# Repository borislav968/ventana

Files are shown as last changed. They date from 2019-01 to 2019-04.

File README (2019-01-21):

This folder contains the crank power window controller firmware source code and PCB design.

This controller replaces the crank window mechanism and is intended to be applied in retro cars where the owner
doesn't want to install the buttons when installing the power window drive.

The main features are:
- soft motor start and stop.
- full opening or closing mode without holding the lever.
- an input from the car alarm or central lock system for closing the windows.
- protection from motor overload or short circuit with a current sensor.
- protection from output short circuit to the ground or battery.

© Boris Malkov 2019

This program is free software: you can redistribute it and/or modify
    it under the terms of the GNU General Public License as published by
    the Free Software Foundation, either version 3 of the License, or
    (at your option) any later version.

    This program is distributed in the hope that it will be useful,
    but WITHOUT ANY WARRANTY; without even the implied warranty of
    MERCHANTABILITY or FITNESS FOR A PARTICULAR PURPOSE.  See the
    GNU General Public License for more details.

    You should have received a copy of the GNU General Public License
    along with this program.  If not, see <https://www.gnu.org/licenses/>.

В этой папке находятся исходные тексты ПО и чертежи печатной платы контроллера электростеклоподъёмника.

Контроллер устанавливается на место штатного механизма ручного стеклоподъёмника и использует его поворотную рукоятку,
прездназначен для установки на ретро-автомобили, где использование кнопок неуместно.

Основные функции:
- плавный пуск и остановка двигателя привода.
- доводка до полного открытия и закрытия без удерживания рукоятки.
- вход для подключения к охранной системе или центральному замку для закрытия окон.
- зашита от перегрузки или КЗ электродвигателя.
- защита от замыкания выходов на массу или плюсовой провод.

© Борис Мальков 2019

Это свободная программа: вы можете перераспространять ее и/или изменять
   ее на условиях Стандартной общественной лицензии GNU в том виде, в каком
   она была опубликована Фондом свободного программного обеспечения; либо
   версии 3 лицензии, либо (по вашему выбору) любой более поздней версии.

   Эта программа распространяется в надежде, что она будет полезной,
   но БЕЗО ВСЯКИХ ГАРАНТИЙ; даже без неявной гарантии ТОВАРНОГО ВИДА
   или ПРИГОДНОСТИ ДЛЯ ОПРЕДЕЛЕННЫХ ЦЕЛЕЙ. Подробнее см. в Стандартной
   общественной лицензии GNU.

   Вы должны были получить копию Стандартной общественной лицензии GNU
   вместе с этой программой. Если это не так, см.
   <https://www.gnu.org/licenses/>.

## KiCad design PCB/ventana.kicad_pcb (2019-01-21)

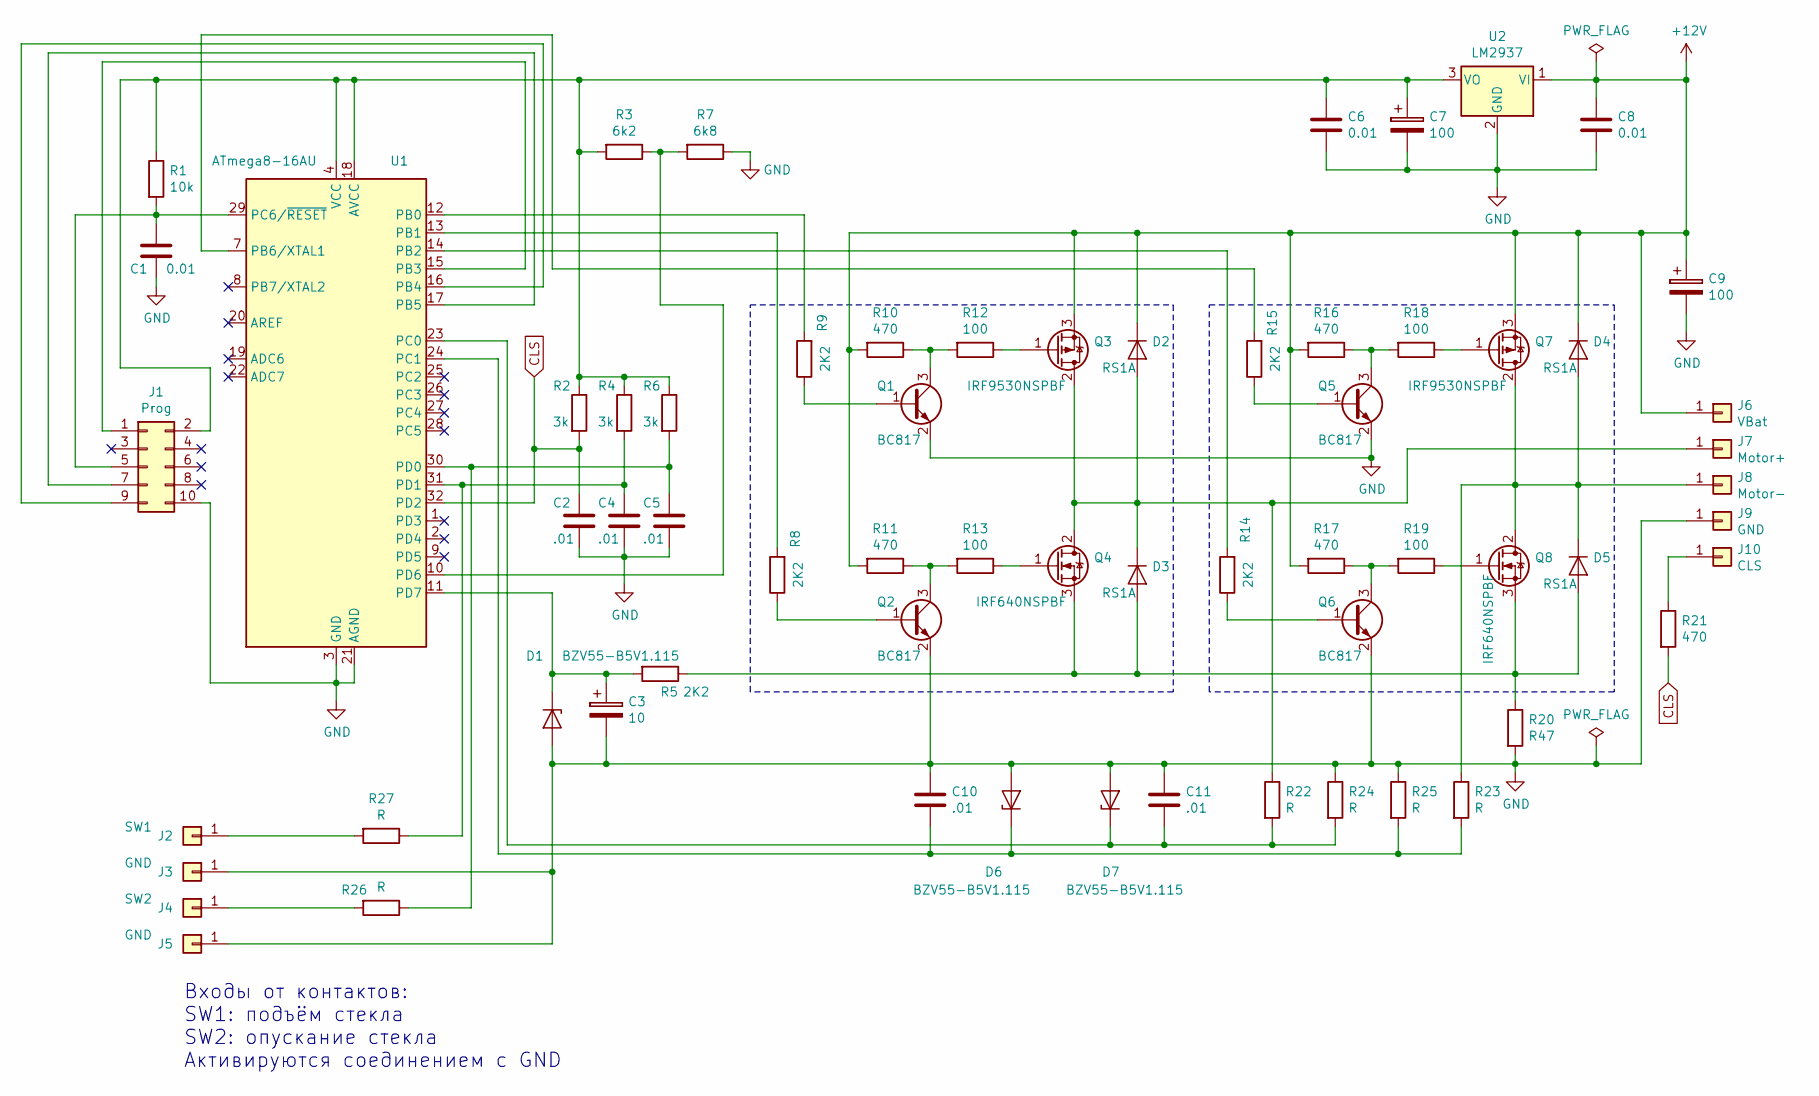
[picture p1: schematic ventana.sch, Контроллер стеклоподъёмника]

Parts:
C1, C6, C8: 0.01; C_1206_3216Metric
C2, C4, C5, C10, C11: .01; C_1206_3216Metric
C3: 10; CP_Elec_5x5.3
C7, C9: 100; CP_Elec_8x6.9
D1, D6, D7: BZV55-B5V1.115; D_SOD-123
D2, D3, D4, D5: RS1A; D_SMA
J1: Prog; conn_2_5
J2: SW1; PinHeader_1x01_P2.54mm_Vertical
J3, J5, J9: GND; PinHeader_1x01_P2.54mm_Vertical
J4: SW2; PinHeader_1x01_P2.54mm_Vertical
J6: VBat; PinHeader_1x01_P2.54mm_Vertical
J7: Motor+; PinHeader_1x01_P2.54mm_Vertical
J8: Motor-; PinHeader_1x01_P2.54mm_Vertical
J10: CLS; PinHeader_1x01_P2.54mm_Vertical
Q1, Q2, Q5, Q6: BC817; SOT-23
Q3, Q7: IRF9530NSPBF; TO-263-2
Q4, Q8: IRF640NSPBF; TO-263-2
R1: 10k; R_1206_3216Metric
R2, R4, R6: 3k; R_1206_3216Metric
R3: 6k2; R_1206_3216Metric
R5, R8, R9, R14, R15: 2K2; R_1206_3216Metric
R7: 6k8; R_1206_3216Metric
R10, R11, R16, R17, R21: 470; R_1206_3216Metric
R12, R13, R18, R19: 100; R_1206_3216Metric
R20: R47; R_Axial_Power_L25.0mm_W9.0mm_P30.48mm
R22, R23, R24, R25, R26, R27: R; R_1206_3216Metric
U1: ATmega8-16AU; AtMega8_TQFP32
U2: LM2937; SOT-223

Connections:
+12V: C8.1, C9.1, D2.1 (K), D4.1 (K), J6.1, Q3.3 (S), Q7.3 (S), R10.2, R11.2, R16.2, R17.2, U2.1 (VI)
CLS: C2.1, R2.2, R21.2, U1.32 (PD2)
GND: C1.2, C2.2, C3.2, C4.2, C5.2, C6.2, C7.2, C8.2, C9.2, C10.1, C11.1, D1.2 (A), D6.2 (A), D7.2 (A), J1.10, J3.1, J5.1, J9.1, Q1.2 (E), Q2.2 (E), Q5.2 (E), Q6.2 (E), R7.1, R20.2, R24.1, R25.1, U1.3 (GND), U1.5 (GND), U1.21 (AGND), U2.2 (GND)
unnamed: C1.1, J1.5, R1.2, U1.29 (PC6/~RESET)
unnamed: C3.1, D1.1 (K), R5.2, U1.11 (PD7)
unnamed: C4.1, R4.2, R27.1, U1.31 (PD1)
unnamed: C5.1, R6.2, R26.1, U1.30 (PD0)
unnamed: C6.1, C7.1, J1.2, R1.1, R2.1, R3.2, R4.1, R6.1, U1.4 (VCC), U1.6 (VCC), U1.18 (AVCC), U2.3 (VO)
unnamed: C10.2, D6.1 (K), R23.2, R25.2, U1.24 (PC1)
unnamed: C11.2, D7.1 (K), R22.2, R24.2, U1.23 (PC0)
unnamed: D2.2 (A), D3.1 (K), J7.1, Q3.2 (D), Q4.2 (D), R22.1
unnamed: D3.2 (A), D5.2 (A), Q4.3 (S), Q8.3 (S), R5.1, R20.1
unnamed: D4.2 (A), D5.1 (K), J8.1, Q7.2 (D), Q8.2 (D), R23.1
unnamed: J1.1, U1.15 (PB3)
unnamed: J1.7, U1.17 (PB5)
unnamed: J1.9, U1.16 (PB4)
unnamed: J2.1, R27.2
unnamed: J4.1, R26.2
unnamed: J10.1, R21.1
unnamed: Q1.1 (B), R9.1
unnamed: Q1.3 (C), R10.1, R12.2
unnamed: Q2.1 (B), R8.1
unnamed: Q2.3 (C), R11.1, R13.2
unnamed: Q3.1 (G), R12.1
unnamed: Q4.1 (G), R13.1
unnamed: Q5.1 (B), R15.1
unnamed: Q5.3 (C), R16.1, R18.2
unnamed: Q6.1 (B), R14.1
unnamed: Q6.3 (C), R17.1, R19.2
unnamed: Q7.1 (G), R18.1
unnamed: Q8.1 (G), R19.1
unnamed: R3.1, R7.2, U1.10 (PD6)
unnamed: R8.2, U1.13 (PB1)
unnamed: R9.2, U1.12 (PB0)
unnamed: R14.2, U1.14 (PB2)
unnamed: R15.2, U1.7 (PB6/XTAL1)

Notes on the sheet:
Входы от контактов: SW1: подъём стекла SW2: опускание стекла Активируются соединением с GND

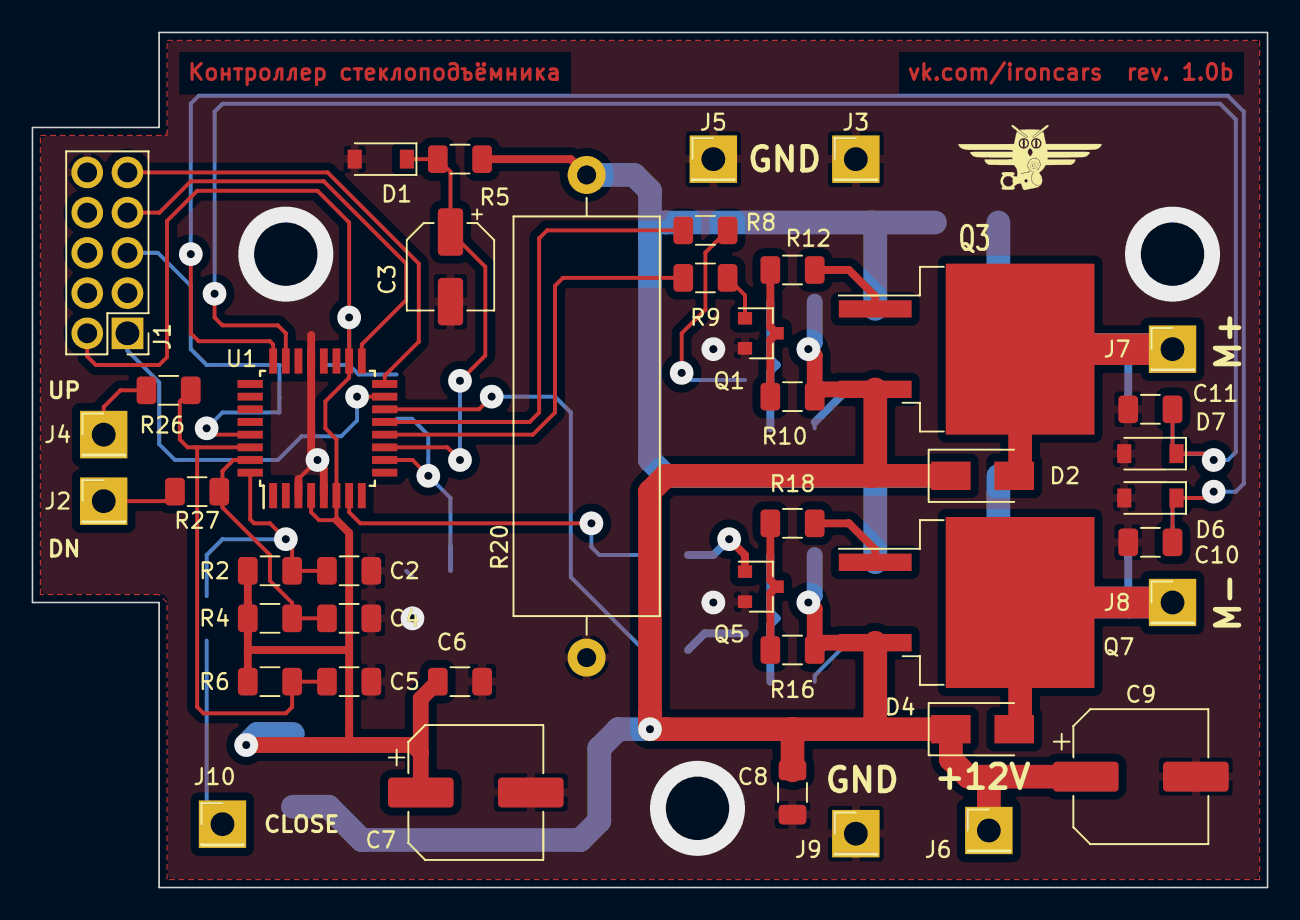
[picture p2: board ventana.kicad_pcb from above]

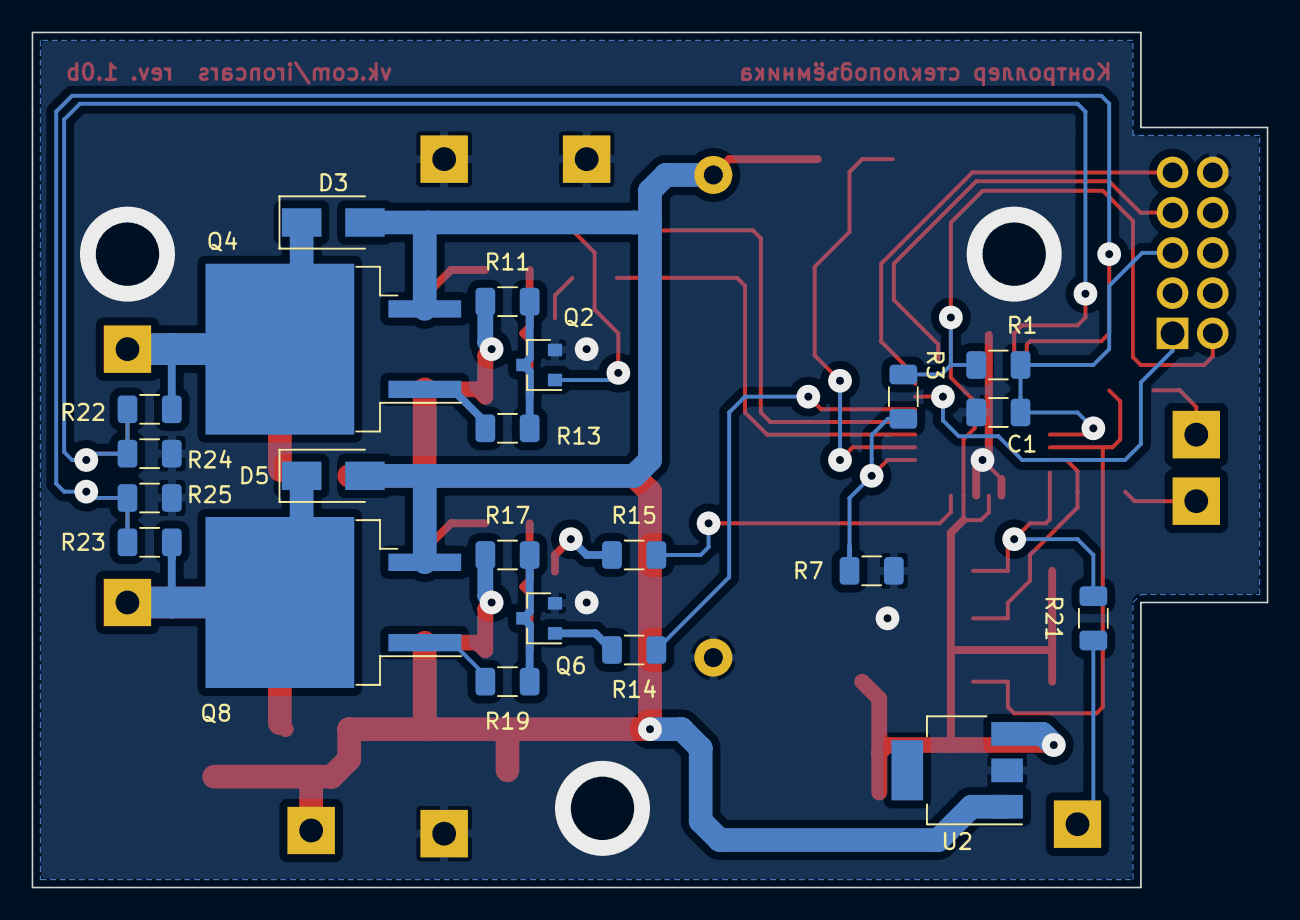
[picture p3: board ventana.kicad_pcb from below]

Board: 2 copper layers, 78.0 x 54.0 mm, 65 parts (22 on the bottom side), 36 nets.

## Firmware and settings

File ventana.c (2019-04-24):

/*
 * ventana.c
 *
 * Created on: 27 сент. 2018 г.
 *      Author: Borislav Malkov
 */

#include <avr/io.h>
#include <avr/interrupt.h>
#include "motor.h"
#include "switch.h"
#include "defines.h"
#include "fuses.h"
#include "driver.h"

// TODO: Make those two functions one
// Move the window up
/**
void moveup () {
    if (state & ST_DIR) {           // if direction is the same in state
        if ((state & ST_EDGE) || (state & ST_HOLD)) return; // do nothing if it already has reached the edge
        if (state & ST_MOVE) {      // restart motor if it was in spindown state
            state |= ST_SPDUP;
            return;
        }
    }
    if (state & ST_MOVE) {          // if direction was other in state
        state &= ~ST_HOLD;
        motor_stop();               // spin the motor down
        while (speed) {};           // wait for it to stop
    }
    state &= ~(ST_EDGE | ST_HOLD);  // clear edge and hold flags
    state |= ST_DIR;                // start motor in needed direction
    motor_start();
}

// Move the window down
void movedn () {
    if (!(state & ST_DIR)) {           // if direction is the same in state
        if ((state & ST_EDGE) || (state & ST_HOLD)) return; // do nothing if it already has reached the edge
        if (state & ST_MOVE) {      // restart motor if it was in spindown state
            state |= ST_SPDUP;
            return;
        }
    }
    if (state & ST_MOVE) {          // if direction was other in state
        state &= ~ST_HOLD;
        motor_stop();               // spin the motor down
        while (speed) {};           // wait for it to stop
    }
    state &= ~(ST_EDGE | ST_HOLD);  // clear edge and hold flags
    state &= ~ST_DIR;               // start motor in needed direction
    motor_start();
}
**/

// Experimental
void move (uchar direction) {
    //if (direction) direction = ST_DIR;
    if (direction ? (state & ST_DIR) : (!(state & ST_DIR))) {           // if direction is the same in state
        if ((state & ST_EDGE) || (state & ST_HOLD)) return; // do nothing if it already has reached the edge
        if (state & ST_MOVE) {      // restart motor if it was in spindown state
            state |= ST_SPDUP;
            return;
        }
    }
    if (state & ST_MOVE) {          // if direction was other in state
        state &= ~ST_HOLD;
        motor_stop();               // spin the motor down
        while (speed) {};           // wait for it to stop
    }
    state &= ~(ST_EDGE | ST_HOLD);  // clear edge and hold flags
    if (direction) state |= ST_DIR; else state &= ~ST_DIR;
    state = direction ? (state | ST_DIR) : (state & ~ST_DIR);             // start motor in needed direction
    motor_start();
}


// Enter 'hold' mode - now motor will continue working even if no input from switch
void hold () {
    if (state & (ST_EDGE | ST_MOVE)) state |= ST_HOLD;
}

void rollback () {
    uchar t;
    t = max_duration;
    max_duration = t/6;
    state &= ~(ST_DIR | ST_EDGE);
    //movedn();
    move(0);
    while (state & ST_MOVE);
    max_duration = t;
    state = 0;
}

ISR (TIMER1_CAPT_vect) {

}

// Enter sleep mode
void sleep () {
    // timer1 will wake the MCU after ~1/15 second
    TCCR1A = 0;
    TCCR1B = (1<<WGM13) | (1<<WGM12) | (1<<CS11) | (1<<CS10);   // set prescaler 64
    TCNT1 = 0;
    ICR1 = 0x1046;          // set 'top' to 4166
    TIMSK |= (1<<TICIE1);   // allow compare match interrupt
    asm("sleep");           // go to idle mode
    TIMSK &= ~(1<<TICIE1);  // disable timer2 after awakening
    TCCR1B = 0;
    bridge_chk();           // check if there are no shorts of bridge middle points to +12V
}

int main () {
    unsigned char input = 0, prev = 0;
    // Allow global interrupts
    asm("sei");
    // Set up the idle mode
    MCUCR &= ~((1<<SM2) | (1<<SM1) | (1<<SM0));
    MCUCR |= (1<<SE);
    bridge = (1<<BR_LL) | (1<BR_LR);
    bridge_update();
    init_switch_port(); // See switch.c for details
    init_motor();
    ACSR |= (1<<ACD);   // Disable analog comparator for energy saving when idle

    while (1) {
        if (state & ST_BACK) rollback();
        input = poll_switch();  // Poll current command from switch
        if (input != prev) {    // Do nothing if it didn't change
            switch (input) {
                case CMD_UP:    // Move up
                    //moveup();
                    move(1);
                    break;
                case CMD_DN:    // Move down
                    //movedn();
                    move(0);
                    break;
                case CMD_HOLD:  // Enable 'hold' mode
                    hold();
                    break;
                case CMD_CLOSE: // Move up and Hold together - for the alarm system which will close the windows
                    //moveup();
                    move(1);
                    hold();
                    break;
                case 0:         // No commands - if not in 'hold' state, stop the motor
                    if (!(state & ST_HOLD)) {
                        motor_stop();
                    }
                    break;
                default:        // For some weird situations =)
                    state = 0;
                    motor_stop();
            }
            prev = input;
        } //else if (!(input || speed)) sleep(); // go to idle mode if nothing is happening
    }
}

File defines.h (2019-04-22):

/*
 * defines.h
 *
 * Created on: 27 сент. 2018 г.
 *      Author: Borislav Malkov
 */

#ifndef DEFINES_H
#define DEFINES_H

#define uchar   unsigned char
#define uint    unsigned int

#define ON          0x01
#define OFF         0x00

#define ST_MOVE     (1<<0)
#define ST_DIR      (1<<1)
#define ST_HOLD     (1<<2)
#define ST_EDGE     (1<<3)
#define ST_SPDUP    (1<<4)
#define ST_TMOUT    (1<<5)
#define ST_LEARN    (1<<6)
#define ST_BACK     (1<<7)

#define CMD_UP      (1<<0)
#define CMD_DN      (1<<1)
#define CMD_HOLD    (CMD_UP | CMD_DN)
#define CMD_CLOSE   (1<<2)

#define BR_LR       0
#define BR_UR       1
#define BR_LL       2
#define BR_UL       3
#define BR_ERROR    0b11110000

#if defined __AVR_ATmega8__
    #define SW_PORT     PORTD
    #define SW_DDR      DDRD
    #define SW_PIN      PIND
    #define SW_0        PD0
    #define SW_1        PD1
    #define SW_2        PD2
    #define MT_PORT     PORTB
    #define MT_DDR      DDRB
    #define MT_PIN      PINB
    #define MT_UL       PB0
    #define MT_UR       PB6
    #define MT_LL       PB1
    #define MT_LR       PB2
    #define CMP_PORT    PORTD
    #define CMP_DDR     DDRD
    #define AIN0        PD6
    #define AIN1        PD7
    #define PORT_ADC    PORTC
    #define DDR_ADC     DDRC
    #define ADC_L       PC0
    #define ADC_R       PC1
# else
    #error "This source is for atmega8 and atmega16 MCUs"
#endif

// motor run max duration, ~seconds
#define T_DURATION 15
#define T_MIN_DURATION 1

// PWM resolution - the bigger it is, the lower will be PWM frequency.
// Freq = F_CPU/N*(PWM_RES+1) = 8000000 / 8 * (63 + 1) = 15625Hz
// Also affects spinup/spindown time
#define PWM_RES 0x3F

// Max output voltage measured by ADC
#define MAX_VOLTAGE 170

// For short circuit protection functions
#define LO_THRESHOLD 20
#define HI_THRESHOLD 50

#define REC_LG 50

typedef uchar record[REC_LG];

typedef struct {
    uchar start;
    uchar end;
} interval;


#endif

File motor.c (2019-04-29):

/*
 * motor.c
 *
 * Created on: 27 сент. 2018 г.
 *      Author: Borislav Malkov
 */

#include <avr/io.h>
#include <avr/interrupt.h>
#include <avr/eeprom.h>
#include "defines.h"
#include "driver.h"
//#include <stdlib.h>
//#include <stdio.h>
#include <util/delay.h>
#include "util.h"


// Device state bits are stored here
volatile unsigned char state = 0;

// Current speed for PWM control
volatile unsigned char speed = 0;

// Time counter for motor run time limiting
volatile uint duration;

// Maximum motor run duration
volatile uint max_duration;

record journal;                     // motor voltage log
uchar logptr = 0;                   // last log record index
uchar logsize = 0;                  // size of the last log
interval time_int = {0, REC_LG-1};  // voltage drop measurement interval
interval full_int = {0, REC_LG-1};  // full interval
uint hardness = 0;                  // measured voltage drop function square
uchar voltage_normal = 0;           // measured motor voltage during run

void savelog (uchar v) {
    journal[logptr] = v;
    logptr = (logptr + 1 + REC_LG) % REC_LG;
    if (logsize < REC_LG) logsize++;
}

void analyze (uchar j[]) {
    uint h;
    signed int dv = 0;
    interval volt_int;
    if (logsize < (REC_LG - time_int.start) || ((max_duration - duration) < 20)) return;
    rec_wrap(journal, logptr);
    rec_filter(journal, 1);
    rec_filter(journal, 0);
    volt_int.start = REC_LG - logsize;
    volt_int.end = REC_LG - 1;
    dv = (voltage_normal - rec_volt_margins(journal, volt_int).end) * 10;
    rec_relative(journal, time_int);
    h = rec_hardness(j, time_int) + dv;
    if (h < hardness) state |= ST_BACK;
}

// Soft stop - just remove ST_SPDUP bit
// The rest will be done in Timer 0 interrupt
void motor_stop () {
    state &= ~ST_SPDUP;
}

// Timer 0 interrupt
// PWM control routine
ISR (TIMER0_OVF_vect) {
    unsigned char s = speed;    // remember current speed
    savelog(out_voltage());
    // Increase or decrease speed depending on ST_SPDUP
    if (state & ST_SPDUP) {
        if (speed < PWM_RES) speed++;
    }
    else
    {
        if (speed > 0) speed--;
    };
    // Set PWM duty on appropriate channel if speed has changed
    if ((s != speed) || (speed == 0)) *(state & ST_DIR ? &OCR1A : &OCR1B) = speed;
    // Complete stop routine
    if (speed == 0) {
        // Disable timers and interrupts
        TIMSK &= ~(1<<TOIE0);
        TCCR0 = 0;
        TCCR1A = 0;
        TCCR1B = 0;
        TCCR2 = 0;
        // Disable bridge drivers
        bridge_update((1<<BR_LL) | (1<<BR_LR));
        // Disable comparator
        ACSR &= ~(1<<ACIE);
        ACSR |= (1<<ACD);
        // Clear ST_MOVE flag
        state &= ~ST_MOVE;
        if ((state & ST_DIR) && (state & ST_EDGE) && (!(state & ST_LEARN)) && (!(state & ST_TMOUT))) analyze(journal);
    }
}

// Timer2 overflow
ISR (TIMER2_OVF_vect) {
    // Check if it's time to stop motor
    if (duration > 0) {
        duration--;
    }
    else
    {
        state |= ST_TMOUT;
        TIMSK &= ~(1<<TOIE2);
        // Acting like current sensor triggered
        state |= ST_EDGE;
        // Immediate stop without soft spindown
        if (!((state & ST_LEARN) || (state & ST_BACK))) speed = 0;
        state &= ~(ST_SPDUP | ST_HOLD);
    }
}

// Comparator output falling edge
// Occurs when voltage at AIN1 > AIN0 (motor overload)
ISR (ANA_COMP_vect) {
    state |= ST_EDGE;
    speed = 0;
    state &= ~(ST_SPDUP | ST_HOLD);
}

void motor_start () {
    logptr = 0;
    logsize = 0;
    // Set up comparator input pins
    CMP_PORT &= ~((1<<AIN0) | (1<<AIN1));
    CMP_DDR  &= ~((1<<AIN0) | (1<<AIN1));
    // Enable analog comparator
    ACSR &= ~(1<<ACD);
    // Enable comparator multiplexer
    SFIOR &= ~(1<<ACME);
    // Enable interrupt on falling edge
    // Will fire if AIN0 > AIN1 (AIN1 has to be on tunable reference voltage)
    ACSR  |=  (1<<ACIS1);
    // Enable comparator interrupt for overcurrent protection
    ACSR |= (1<<ACIE);
    // output pins for drivers
    MT_DDR |= (1<<MT_UL) | (1<<MT_UR) | (1<<MT_LL) | (1<<MT_LR);
    // Enable speed up and move bits in status
    state |= ST_SPDUP | ST_MOVE;
    state &= ~ST_TMOUT;
    // Timer 0 is for motor speed increase/decrease
    // Spinup time = PWM_RES * ((N*256)/F_CPU), timer0 prescaler N is now 256
    TCCR0 |= (1<<CS02);// | (1<<CS00);
    // Enable timer 0 overflow interrupt
    TIMSK |= (1<<TOIE0);
    // Timer 1 is used for PWM control of the motor
    // Mode 14 - fast PWM with top at ICR1
    TCCR1A = (1<<WGM11);
    TCCR1B = (1<<WGM12) | (1<<WGM13);
    ICR1 = PWM_RES;
    // timer1 prescaler 1
    // F_PWM will be F_CPU/(N*(PWM_RES+1)) = 1000000/64 = 15625 Hz
    TCCR1B |= (1<<CS11);
    // Now raising COM1A1 and COM1B1 in TCCR1A will connect PB1 or PB2 to the timer
    // Duty can be adjusted by changing OCR1A and OCR1B
    // Now start the motor in needed direction
    bridge_update((state & ST_DIR) ? (0<<BR_LR) | (1<<BR_UR) : (0<<BR_LL) | (1<<BR_UL));
    TCCR1A = state & ST_DIR ? TCCR1A | ((1<<COM1A0) | (1<<COM1A1)) : TCCR1A | ((1<<COM1B0) | (1<<COM1B1));
    // Timer 2 is for motor run time limiting (e.g. if stop by current sensor comparator didn't happen)
    duration = max_duration;
    TCCR2 = (1<<CS22) | (1<<CS21) | (1<<CS20);  // Set prescaling to 1/1024 ~ 30.5 overflows/sec
    TIMSK |= (1<<TOIE2);                        // Allow overflow interrupt
}
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

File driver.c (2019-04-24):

/*
 * driver.c
 *
 * Low-level driver for the H-bridge
 *
 * Created on: 19 дек. 2018 г.
 *      Author: Borislav Malkov
 */

#include <avr/io.h>
#include <avr/interrupt.h>
#include <util/delay.h>
#include "defines.h"
#include "util.h"
#include <stdlib.h>

// Stores the H-bridge state
// 3:0 are for the state (on/off) of UL, LL, UR, LR
// 7:4 are for errors of UL, LL, UR, LR
volatile uchar bridge;

// Returns the actual state of bridge controlling pins
uchar get_bridge_state () {
    uchar res;
    res  =   ((MT_PIN>> MT_UL) & 0x01)<<BR_UL;
    res |= (((~MT_PIN)>>MT_LL) & 0x01)<<BR_LL;
    res |=   ((MT_PIN>> MT_UR) & 0x01)<<BR_UR;
    res |= (((~MT_PIN)>>MT_LR) & 0x01)<<BR_LR;
    return res;
}

// Turns the ADC on or off
void adc (uchar on) {
    if (on) {
        DDR_ADC &= ~((1<<ADC_L) | (1<<ADC_R));
        PORT_ADC &= ~((1<<ADC_L) | (1<<ADC_R));
        ADCSRA = (1<<ADEN) | (1<<ADPS2) | (1<<ADPS1);
        ADMUX = (1<<REFS0) | (1<<ADLAR);
    } else {
        ADMUX = 0;
        ADCSRA &= ~(1<<ADEN);
    }
}

// Measures the voltage at middle points of the bridge
// 'mux' selects the ADC input
uchar get_voltage (uchar mux) {
    ADMUX &= 0b11110000;            // zero the 3:0 ADMUX bits
    ADMUX |= (mux & 0b00001111);    // raise 3:0 bits as needed
    _delay_ms(1);                   // wait for the signal to get stable
    ADCSRA |= (1<<ADSC);            // start the conversion
    while (ADCSRA & (1<<ADSC)) {};  // ...and wait for it to end
    return ADCH;
}

uchar out_voltage () {
    uchar a, b;
    adc(ON);
    a = get_voltage(0x00);
    b = get_voltage(0x01);
    adc(OFF);
    if (a == b) return 0;
    return a > b ? a - b : b - a;
}

// Since the actual FET outputs not necessarily are matching to 'bridge' bits
// this one will return actual pin of the MOSFET by it's number in the 'bridge'
uchar which_fet (uchar i) {
    switch (i) {
        case 0:
            return MT_LR;
        case 1:
            return MT_UR;
        case 2:
            return MT_LL;
        case 3:
            return MT_UL;
        default:
            return 0xFF;
    }
}

// Checks if the open MOSFET doesn't cause a short circuit due, for example, bad insulation
void fet_chk (uchar i) {
    uchar fet, voltage;
    uchar k, v[3];
    uchar error = 0;
    if (bridge & (1<<(i+4))) return;            // do nothing if there already is an error on this MOSFET
    if ((bridge>>i) & 0x01) {                   // there's no need to do this check for a closed MOSFET
        fet = which_fet(i);
        adc(ON);                                // turn on the ADC
        //voltage = get_voltage(~(i>>1) & 0x01);  // measure voltage on the left or right side
        for (k = 0; k < 3; k++) {
            v[k] = get_voltage(~(i>>1) & 0x01);
        }
        voltage = median(v);
        if (i & 0x01) {                                             // if it is an upper MOSFET
            if (voltage < (MAX_VOLTAGE - HI_THRESHOLD)) error++;    // it should make the voltage rise, so if it's too low, there's an error
        } else {
            if (voltage > LO_THRESHOLD) error++;                    // lower MOSFET should hold the voltage low
        }
        adc(OFF);                               // turn off the ADC
        if (error == 0) return;                 // if no errors, nothing more to do
        if (!(i & 0x01)) bridge |= (1<<(i+4));  // remember the error in the corresponding bit of 'bridge' var
        MT_PORT = (i & 0x01) ? MT_PORT & ~(1<<fet) : MT_PORT | (1<<fet);    // of course the MOSFET should be closed now
    }
}

// Open or close the MOSFET addressed by 'i'
void fet_ctrl (uchar i) {
    uchar fet;
    if (bridge & (1<<(i+4))) return;    // if there is a stored error, do nothing
    fet = which_fet(i);
    if ((bridge>>i) & 0x01) {           // open a MOSFET
        MT_PORT = (i & 0x01) ? MT_PORT | (1<<fet) : MT_PORT & ~(1<<fet);    // for upper MOSFETs open is '1', for lower ones '0'
    } else {
        MT_PORT = (i & 0x01) ? MT_PORT & ~(1<<fet) : MT_PORT | (1<<fet);    // and vice versa for closing them
    }
}

// updates the  bridge state from 'br' by opening and closing the MOSFETs
// with checking for errors
void bridge_update (uchar br) {
    uchar change, i;
    if (br) bridge = br;                                // if no params, update from the 'bridge' global var
    if (bridge & (1<<BR_UL)) bridge &= ~(1<<BR_LL);     // check if there are no collisions
    if (bridge & (1<<BR_UR)) bridge &= ~(1<<BR_LR);     // we don't want to open lower and upper MOSFETs on the same side
    change = bridge ^ get_bridge_state();               // make the mask of changing bits
    for (i=0; i<4; i++) if (change & (1<<i) && !(bridge & (1<<i))) fet_ctrl(i); // first we do all closing MOSFETs
    for (i=0; i<4; i++) if (change & (1<<i) && bridge & (1<<i)) {               // and after that, all the opening ones
        fet_ctrl(i);
        _delay_ms(20);
        fet_chk(i);
    }
}

// Checks the MOSFETs that are already open
// used when idle, 'cause at idle the lower MOSFETs are open, and we shoud check if there's no shorts from +12V to middle points
void bridge_chk () {
    uchar i;
    for (i=0; i<4; i++) if (bridge & (1<<i)) fet_chk(i);
}

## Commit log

2018-10-06 PWM motor control implemented
2018-10-06 Motor smooth stopping at input signal change
2018-10-09 Add fuses support in code
2018-10-09 Add fuses support in makefile
2018-10-10 Added defines for motor driver pins
2018-10-10 Changed PWM duty control timer0 mode
2018-10-10 Ugly switch debouncing added - to be rewritten
2018-10-10 Motor spinup time now in defines.h
2018-10-10 Now motor restarts when the same direction activated during spindown
2018-12-02 Increased PWM frequency to 15625Hz
2018-12-15 Now lower MOSFETs are open when idle to improve energy saving
2018-12-15 Add KiCAD PCB project
    [ventana.kicad_pcb, ventana.sch]
2018-12-16 Fixed a mistake in the schematic
    [ventana.sch]
2018-12-16 Better motor timings
2018-12-16 Moar energy saving - noow 10mA on idle
2018-12-16 Removed all init functions for motor module
2018-12-17 Added changing of switch direction with saving in EEPROM
2018-12-17 Some energy saving added. Now draws only 9mA on idle
2018-12-17 Load voltage sense circuits added to schematic
    [ventana.sch]
2018-12-18 Schematic and PCB
    [ventana.kicad_pcb, ventana.sch]
2018-12-18 Add protection from short circuit outputs to ground
    [defines.h, motor.c]
2018-12-21 Bridge driver module added
2018-12-22 Bridge driver module now has all planned protection
2018-12-24 Improved voltage control
2018-12-24 Added parts for midpoints voltage measurement
    [ventana.kicad_pcb, ventana.sch]
2019-01-21 PCB rev 1.0b
    [ventana.kicad_pcb, ventana.sch]
2019-01-30 Pins redefined for the new PCB design
2019-04-29 Works correctly, installed on 965i
    [motor.c]
